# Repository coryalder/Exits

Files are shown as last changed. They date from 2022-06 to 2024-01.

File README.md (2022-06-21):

# HEAR

### ⚠️ THIS MODULE WORKS, BUT HASN'T BEEN TESTED THUROUGHLY YET ⚠️

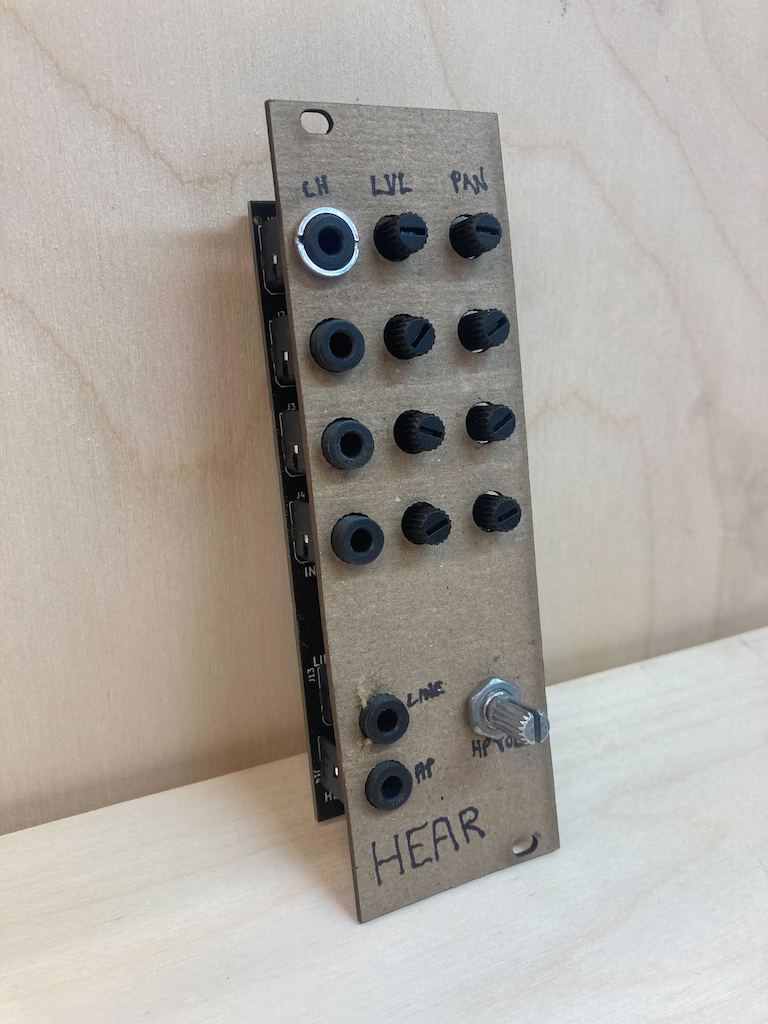
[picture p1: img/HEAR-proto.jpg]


HEAR is a DIY 8hp eurorack module designed to be the output stage of your patches. It has a 4 channel mixer with individual pan and level controls, and line and headphone outputs.

The project was derived from the [Exits](https://github.com/ramphands/Exits) module. Exits was a combination of the lines mixer project [Nearness](https://github.com/sarnesjo/nearness) and the [Forestcaver headphone amp](https://github.com/forestcaver/Analog-Voice/tree/master/AJH_Headphone_Amp). For HEAR The patch-based stereo panning of Exits and nearness was changed out for individual pan and level controls for 4 tracks, and the Forestcaver headphone amp (based on the NJM4556AV-TE1 opamp) was changed out for a headphone amp loosely based on Chu Moy's famous ["CMoy" design](https://web.archive.org/web/20021223020724/http://headwize2.powerpill.org/projects/showproj.php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) - in this case using the RC4580 instead of the OPA134 for availability and experimentation reasons. The module was expanded from 4hp to 8hp to accomodate the extra knobs. I also switched from 1/4" jacks for the two outputs - to 1/8" jacks for everything. The extra space on the widened input board, along with removing the two tall 1/4" jacks, allowed me to flatten the module from two PCBs to just one.

If you'd like to explore the pan + mix section, circuitjs simulation files are in the [simulations](simulations) directory.

The four mixer channels are DC coupled, so you can use this module to mix CV. The headphone output is not DC coupled, so only the line output will output DC offsets. At maximum volume the headphone output is about 1/10 the input level. J5 and J6 are jumpers - no pins bridged means the mixer has a gain of about 1x. Bridging pins 1 and 2 on both jumpers will set the mixer sections gain to 2/3x in case you're mixing hot signals and want to tone things down a bit. To add gain, you could bridge pins 1+2 and then desolder R17 and R20. That'll set the gain to just shy of 2x.

The following sources were used either directly or as learning material to construct the panning and mixing section:

- [Audio Signal Mixing](https://sound-au.com/articles/audio-mixing.htm) By Rod Elliott - a fantastic explainer of mixing circuits
- Erica Synths DIY eurorack [Output and Mixer](https://github.com/erica-synths/diy-eurorack) modules
- [Befaco Hexmix](http://www.befaco.org/hexmix/)

## Schematic and PCBs

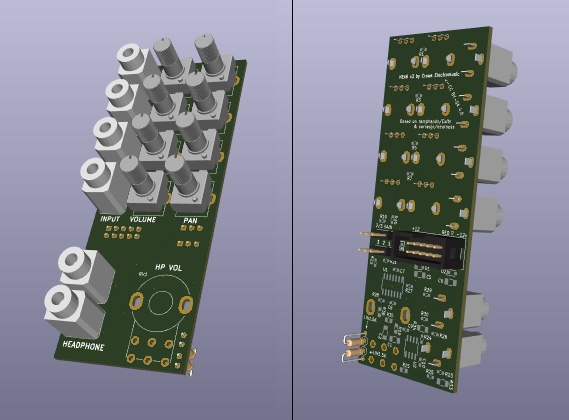
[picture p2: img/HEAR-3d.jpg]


The [kicad](kicad) directory contains the schematic and PCB layout as a KiCad 6 project.

Gerber files are generated by [Bouni's Kicad JLCPCB tools](https://github.com/Bouni/kicad-jlcpcb-tools) - latest files are located in [kicad/jlcpcb](kicad/jlcpcb). These are still untested. This page will be updated when they have been tested and are KNOWN working.

## Panel

The panel for HEAR has been generated by [Crows Eurorack Laser Panels](https://crowselectromusic.com/tools/laser/panels/). The panel definition file is located in the [panel](panel) directory, ypu can use that to generate an SVG or DXF file.

## Revisions and notes 

- Started with this commit of [Exits](https://github.com/ramphands/Exits/tree/e56ce6f3a76ff6dc0b776ba10d0bfae7fea7ace0).
- HEAR's first "complete" post-Exits scheamtic, using passive mixing can be found in the git history [here](https://github.com/crowselectromusic/HEAR/blob/65a9d2693df2f5ae9116ffd591f22e5cf609d3db/exits%20schematic.april12th.pdf). After that I switched to current based mixing, per Rod Elliott's article
- HEAR's first "complete" + "current-based" schematic is [here](https://github.com/crowselectromusic/HEAR/tree/e56ce6f3a76ff6dc0b776ba10d0bfae7fea7ace0).
- Fixed routing so left is on the left and right is on the right, [schematic](https://github.com/crowselectromusic/HEAR/blob/033efc4fa74acb90b556fa5d66f9de59aaeca7dc/exits%20schematic.pdf).

## License

[CC BY-SA 4.0](http://creativecommons.org/licenses/by-sa/4.0/)

To summarize the license linked above - you are free to:

* Share — copy and redistribute the material in any medium or format
* Adapt — remix, transform, and build upon the material
for any purpose, even commercially. 

As long as you abide by the terms of the license which requires:

* Attribution — You must give appropriate credit, provide a link to the license, and indicate if changes were made. You may do so in any reasonable manner, but not in any way that suggests the licensor endorses you or your use.

* ShareAlike — If you remix, transform, or build upon the material, you must distribute your contributions under the same license as the original.

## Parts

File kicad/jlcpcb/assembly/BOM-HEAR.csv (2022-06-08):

Comment | Designator | Footprint | LCSC
TL074 | U1 | SOIC-14_3.9x8.7mm_P1.27mm | C12594
22u | C5,C6 | C_1206_3216Metric_Pad1.33x1.80mm_HandSolder | C12891
100n | C10,C7,C8,C9 | C_0603_1608Metric_Pad1.08x0.95mm_HandSolder | C14663
100K | R15,R16,R35,R36 | R_0805_2012Metric_Pad1.20x1.40mm_HandSolder | C149504
10 | R33,R34 | R_1206_3216Metric_Pad1.30x1.75mm_HandSolder | C17903
0.47uF | C1,C2 | C_1206_3216Metric_Pad1.33x1.80mm_HandSolder | C1868
1N5819HW | D1,D2 | D_SOD-323_HandSoldering | C191023
1K | R25,R26 | R_0603_1608Metric_Pad0.98x0.95mm_HandSolder | C21190
470 | R29,R30 | R_0603_1608Metric_Pad0.98x0.95mm_HandSolder | C23179
50K | R1,R17,R20,R3,R5,R7 | R_0603_1608Metric_Pad0.98x0.95mm_HandSolder | C23196
100K | R19,R38 | R_0603_1608Metric_Pad0.98x0.95mm_HandSolder | C25803
10K | R21,R22,R23,R24,R27,R28 | R_0603_1608Metric_Pad0.98x0.95mm_HandSolder | C25804
RC4580 | U2 | SOIC-8_3.9x4.9mm_P1.27mm | C80100
PJ341 | J2 | PJ341_3.5mm_headphone
10K | RV9 | Potentiometer_Rotary_9mm_Vertical_Single
PJ341 | J1 | PJ341_3.5mm_headphone
PJ341 | J3 | PJ341_3.5mm_headphone
10K Vol | RV2 | Potentiometer_Rotary_9mm_Vertical_Single
10K | RV7 | Potentiometer_Rotary_9mm_Vertical_Single
10K | RV8 | Potentiometer_Rotary_9mm_Vertical_Single
B10K | RV1 | RV1666G-F
10K Vol | RV4 | Potentiometer_Rotary_9mm_Vertical_Single
PJ341 | J13 | PJ341_3.5mm_headphone
10K Vol | RV3 | Potentiometer_Rotary_9mm_Vertical_Single
10K Vol | RV5 | Potentiometer_Rotary_9mm_Vertical_Single
10K | RV6 | Potentiometer_Rotary_9mm_Vertical_Single
PJ341 | J4 | PJ341_3.5mm_headphone
PJ341 | J14 | PJ341_3.5mm_headphone
Euro power header | J12 | IDC-Header_2x05_P2.54mm_Vertical
Attenuator Jumper 1 | J5 | PinHeader_1x03_P2.54mm_Vertical
LIN1.5K | R2 | R_Axial_DIN0207_L6.3mm_D2.5mm_P2.54mm_Vertical
Attenuator Jumper 2 | J6 | PinHeader_1x03_P2.54mm_Vertical
LIN1.5K | R4 | R_Axial_DIN0207_L6.3mm_D2.5mm_P2.54mm_Vertical

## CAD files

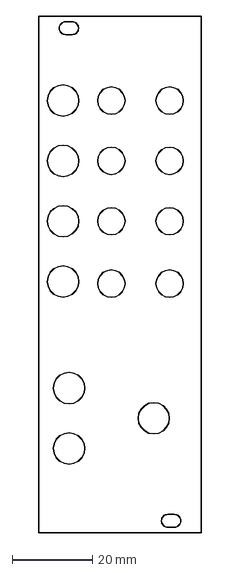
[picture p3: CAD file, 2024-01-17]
panel/HEAR.crowspanel.dxf
40.3 x 128.5 mm

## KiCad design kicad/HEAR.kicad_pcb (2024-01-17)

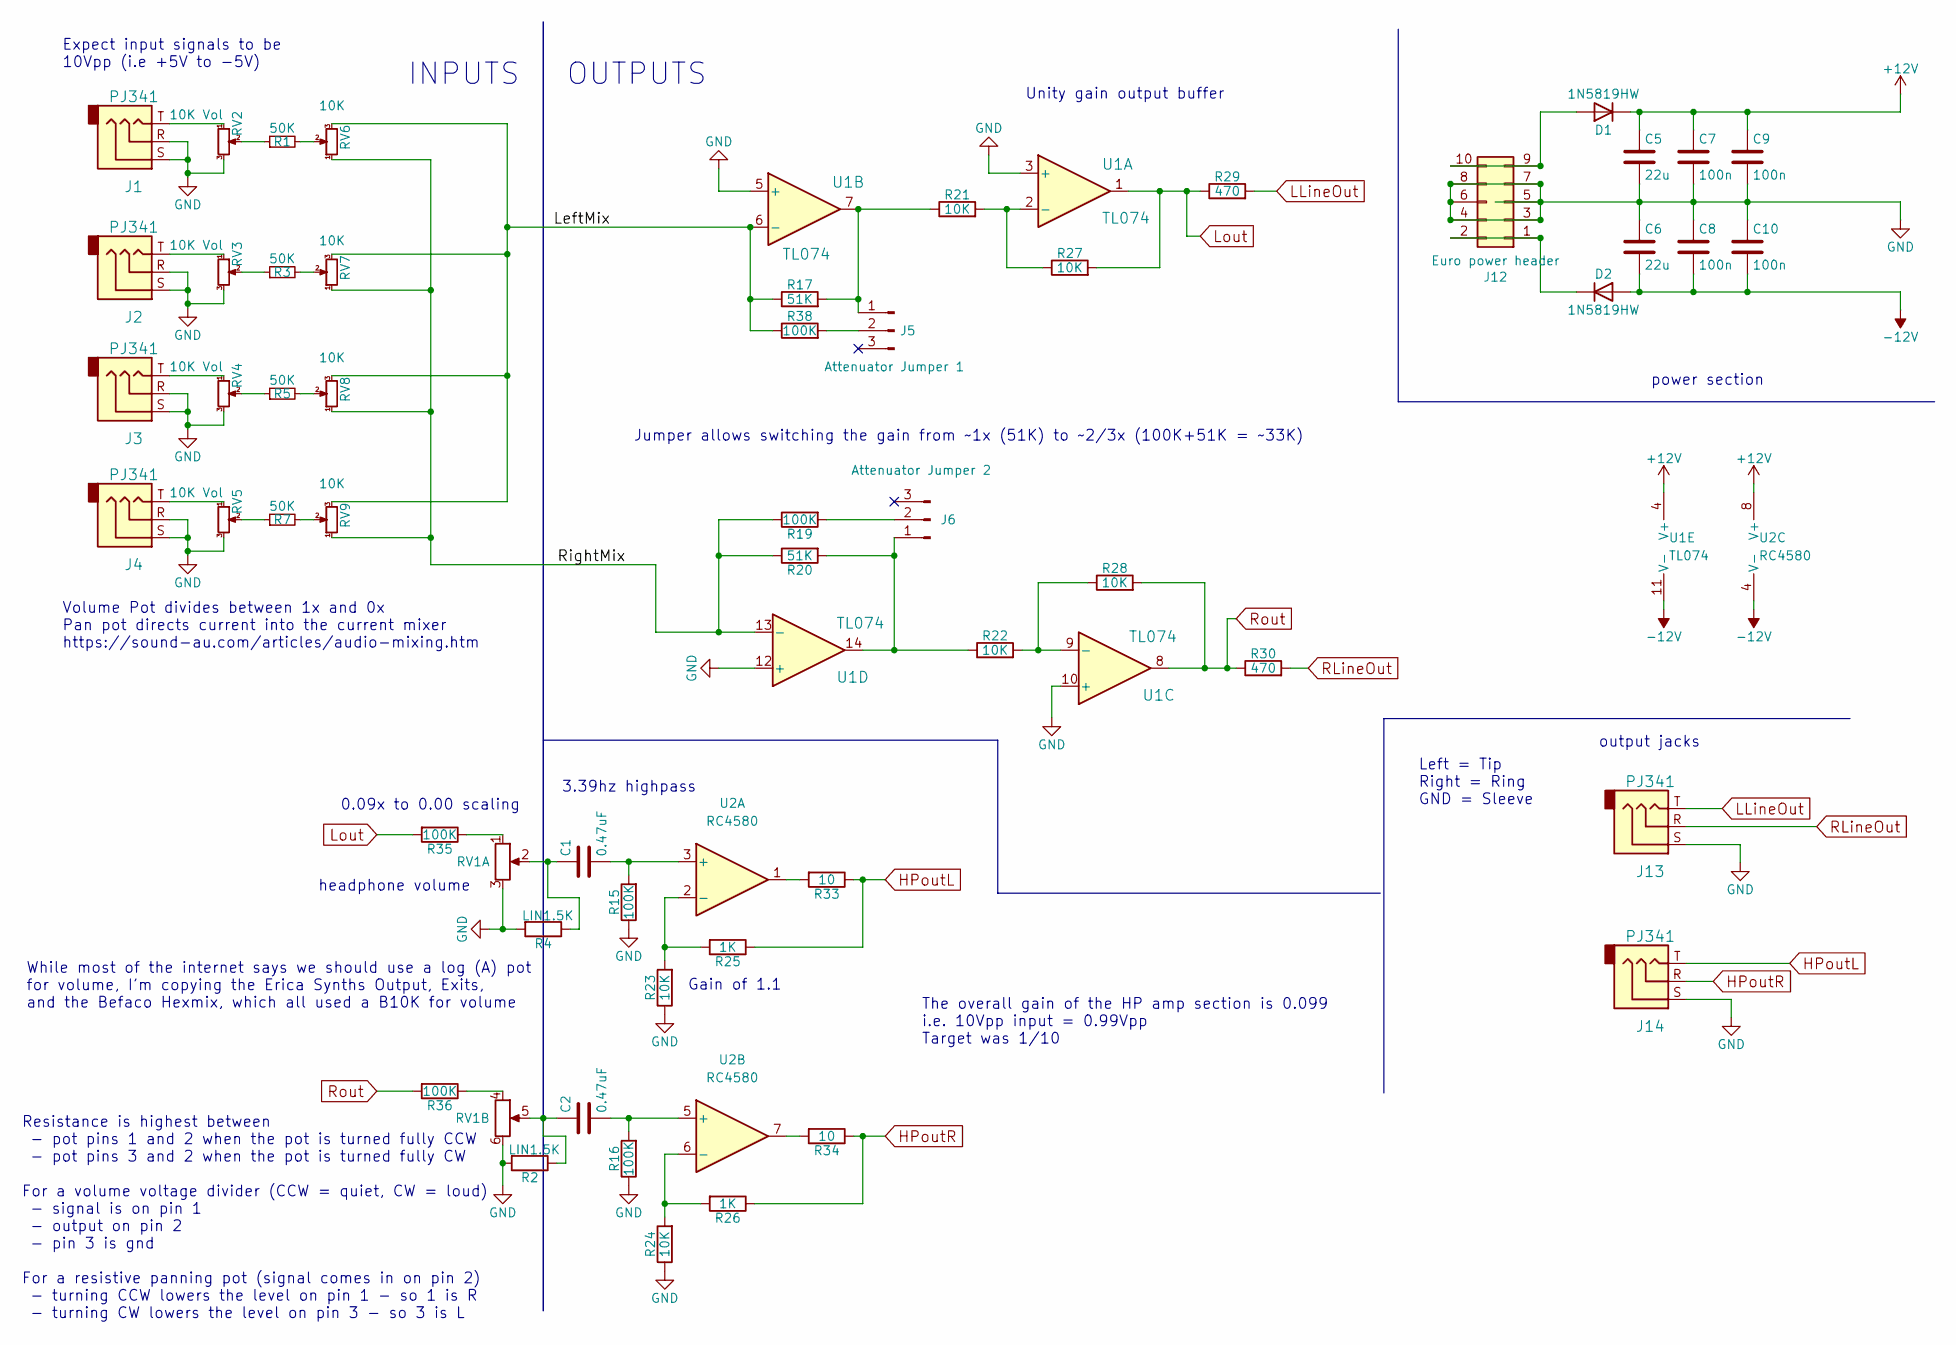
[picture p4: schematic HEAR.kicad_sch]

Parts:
C1, C2: 0.47uF; C_1206_3216Metric_Pad1.33x1.80mm_HandSolder; LCSC C1868
C5, C6: 22u; C_1206_3216Metric_Pad1.33x1.80mm_HandSolder; LCSC C12891
C7, C8, C9, C10: 100n; C_0603_1608Metric_Pad1.08x0.95mm_HandSolder; LCSC C14663
D1, D2: 1N5819HW; D_SOD-323_HandSoldering; LCSC C191023
J1, J2, J3, J4, J13, J14: PJ341; PJ341_3.5mm_headphone
J5: Attenuator Jumper 1; PinHeader_1x03_P2.54mm_Vertical
J6: Attenuator Jumper 2; PinHeader_1x03_P2.54mm_Vertical
J12: Euro power header; IDC-Header_2x05_P2.54mm_Vertical
R1, R3, R5, R7: 50K; R_0603_1608Metric_Pad0.98x0.95mm_HandSolder; LCSC C23196
R2, R4: LIN1.5K; R_Axial_DIN0207_L6.3mm_D2.5mm_P2.54mm_Vertical
R15, R16, R35, R36: 100K; R_0805_2012Metric_Pad1.20x1.40mm_HandSolder; LCSC C149504
R17, R20: 51K; R_0603_1608Metric_Pad0.98x0.95mm_HandSolder; LCSC C23196
R19, R38: 100K; R_0603_1608Metric_Pad0.98x0.95mm_HandSolder; LCSC C25803
R21, R22, R23, R24, R27, R28: 10K; R_0603_1608Metric_Pad0.98x0.95mm_HandSolder; LCSC C25804
R25, R26: 1K; R_0603_1608Metric_Pad0.98x0.95mm_HandSolder; LCSC C21190
R29, R30: 470; R_0603_1608Metric_Pad0.98x0.95mm_HandSolder; LCSC C23179
R33, R34: 10; R_1206_3216Metric_Pad1.30x1.75mm_HandSolder; LCSC C17903
RV1: B10K; RV1666G-F
RV2, RV3, RV4, RV5: 10K Vol; Potentiometer_Rotary_9mm_Vertical_Single
RV6, RV7, RV8, RV9: 10K; Potentiometer_Rotary_9mm_Vertical_Single
U1: TL074; SOIC-14_3.9x8.7mm_P1.27mm; LCSC C12594
U2: RC4580; SOIC-8_3.9x4.9mm_P1.27mm; LCSC C80100

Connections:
+12V: C5.1, C7.1, C9.1, D1.1 (K), U1.4 (V+), U2.8 (V+)
-12V: C6.2, C8.2, C10.2, D2.2 (A), U1.11 (V-), U2.4 (V-)
/LeftMix: R17.1, R38.1, RV6.3, RV7.3, RV8.3, RV9.3, U1.6 (-)
/RightMix: R19.1, R20.1, RV6.1, RV7.1, RV8.1, RV9.1, U1.13 (-)
GND: C5.2, C6.1, C7.2, C8.1, C9.2, C10.1, J1.R, J1.S, J2.R, J2.S, J3.R, J3.S, J4.R, J4.S, J12.3, J12.4, J12.5, J12.6, J12.7, J12.8, J13.S, J14.S, R2.2, R4.2, R15.1, R16.1, R23.1, R24.1, RV1.3, RV1.6, RV2.3, RV3.3, RV4.3, RV5.3, U1.3 (+), U1.5 (+), U1.10 (+), U1.12 (+)
HPoutL: J14.T, R25.1, R33.1
HPoutR: J14.R, R26.1, R34.1
LLineOut: J13.T, R29.2
Lout: R27.2, R29.1, R35.2, U1.1
unnamed: C1.1, R4.1, RV1.2
unnamed: C1.2, R15.2, U2.3 (+)
unnamed: C2.1, R2.1, RV1.5
unnamed: C2.2, R16.2, U2.5 (+)
unnamed: D1.2 (A), J12.9, J12.10
unnamed: D2.1 (K), J12.1, J12.2
unnamed: J1.T, RV2.1
unnamed: J2.T, RV3.1
unnamed: J3.T, RV4.1
unnamed: J4.T, RV5.1
unnamed: J5.1, R17.2, R21.1, U1.7
unnamed: J5.2, R38.2
unnamed: J6.1, R20.2, R22.1, U1.14
unnamed: J6.2, R19.2
unnamed: R1.1, RV2.2
unnamed: R1.2, RV6.2
unnamed: R3.1, RV3.2
unnamed: R3.2, RV7.2
unnamed: R5.1, RV4.2
unnamed: R5.2, RV8.2
unnamed: R7.1, RV5.2
unnamed: R7.2, RV9.2
unnamed: R21.2, R27.1, U1.2 (-)
unnamed: R22.2, R28.1, U1.9 (-)
unnamed: R23.2, R25.2, U2.2 (-)
unnamed: R24.2, R26.2, U2.6 (-)
unnamed: R33.2, U2.1
unnamed: R34.2, U2.7
unnamed: R35.1, RV1.1
unnamed: R36.1, RV1.4
RLineOut: J13.R, R30.2
Rout: R28.2, R30.1, R36.2, U1.8

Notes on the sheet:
The overall gain of the HP amp section is 0.099 i.e. 10Vpp input = 0.99Vpp Target was 1/10
headphone volume
3.39hz highpass
INPUTS
Volume Pot divides between 1x and 0x Pan pot directs current into the current mixer https://sound-au.com/articles/audio-mixing.htm
Left = Tip Right = Ring GND = Sleeve
Unity gain output buffer
0.09x to 0.00 scaling
Gain of 1.1
While most of the internet says we should use a log (A) pot for volume, I'm copying the Erica Synths Output, Exits, and the Befaco Hexmix, which all used a B10K for volume
OUTPUTS
Jumper allows switching the gain from ~1x (51K) to ~2/3x (100K+51K = ~33K)
output jacks
Expect input signals to be 10Vpp (i.e +5V to -5V)
power section
Resistance is highest between - pot pins 1 and 2 when the pot is turned fully CCW - pot pins 3 and 2 when the pot is turned fully CW For a volume voltage divider (CCW = quiet, CW = loud) - signal is on pin 1 - output on pin 2 - pin 3 is gnd For a resistive panning pot (signal comes in on pin 2) - t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

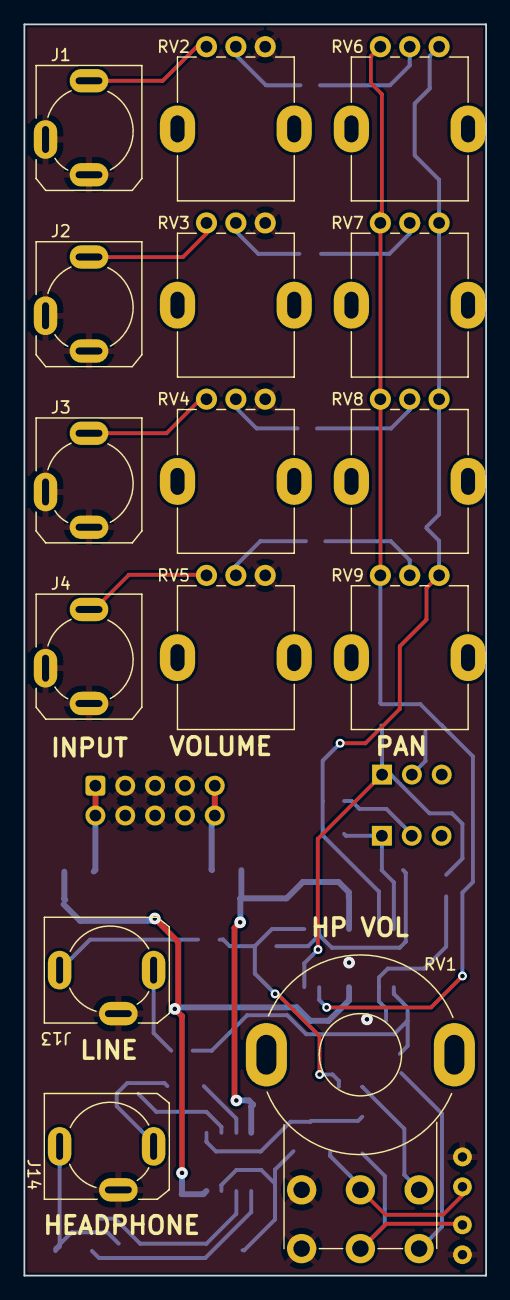
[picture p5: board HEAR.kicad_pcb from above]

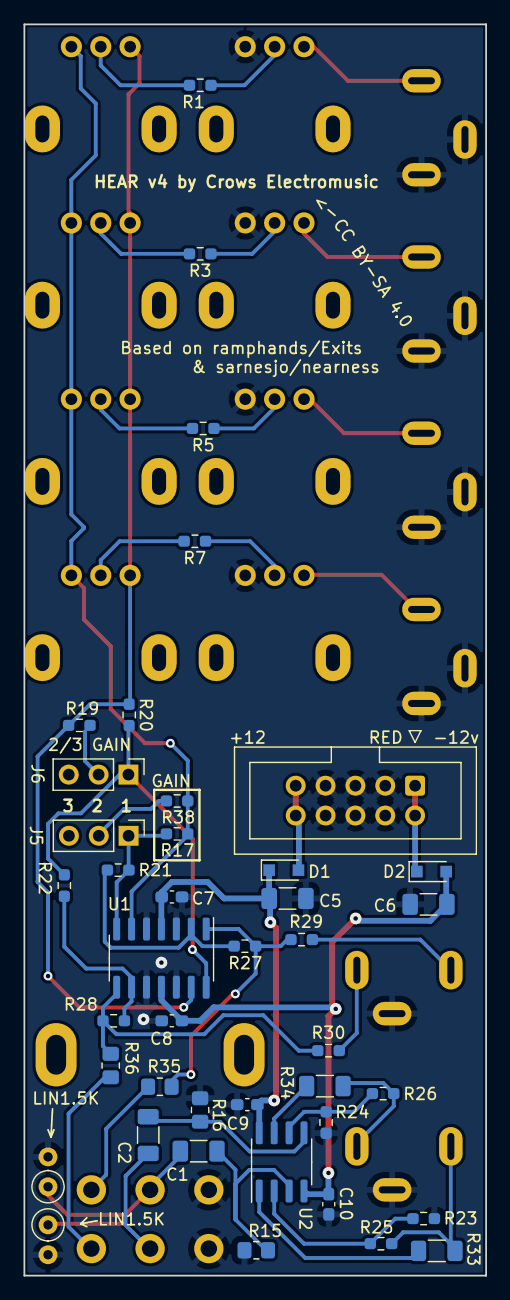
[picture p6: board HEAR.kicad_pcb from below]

Board: 2 copper layers, 39.3 x 106.5 mm, 56 parts (41 on the bottom side), 41 nets.

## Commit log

2022-04-20 note about pot taper
    [exits.kicad_sch]
2022-05-09 removed unused board files
    [exits board A.kicad_pcb, exits board B.kicad_pcb]
2022-05-09 switch to PJ358s for stereo output
    [exits.kicad_pcb, exits.kicad_sch]
2022-06-02 switch to PJ341s, add linearizing Rs
    [exits.kicad_pcb, exits.kicad_sch]
2022-06-02 rename to HEAR
    [HEAR.kicad_pcb, HEAR.kicad_sch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]
2022-06-02 added JLCPCB part numbers
    [HEAR.kicad_sch]
2022-06-02 updated diode footprint for new jlcpart
    [HEAR.kicad_pcb]
2022-06-02 gerbers for v01
    [HEAR-B_Cu.gbl, HEAR-B_Mask.gbs, HEAR-B_Paste.gbp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]
2022-06-02 update ibom
    [exits bom.ods]
2022-06-03 re-route for better symmetry
    [HEAR.kicad_pcb]
2022-06-03 heal broken footprint lib path
2022-06-03 fixed silkscreen errs in footprint
    [HEAR.kicad_pcb]
2022-06-04 footprints submodule
    [HEAR.kicad_pcb, HEAR.kicad_sch]
2022-06-04 3d model for pj341
    [HEAR.kicad_pcb]
2022-06-04 switch to jlcpcb plugin to generate output
    [BOM-HEAR.csv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]
2022-06-04 idk some small change
    [HEAR.kicad_pcb]
2022-06-04 v02 uploaded
    [HEAR.kicad_pcb]
2022-06-04 updated library, new footprint names
    [HEAR.kicad_sch]
2022-06-04 reloaded footprints
    [HEAR.kicad_pcb]
2022-06-08 v3 gerbers (had to swap out a cap, part no longer available
    [BOM-HEAR.csv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]
2023-03-08 Update panel definition file
    [HEAR.crowspanel.dxf]
2023-03-08 Fix pj341 footprint, tidy up spacing of things
    [HEAR.kicad_pcb]
2023-03-16 tweak stereo pot footprint
    [HEAR.kicad_pcb]
2024-01-17 updated panel file to match the pcb
    [HEAR.crowspanel.dxf]
